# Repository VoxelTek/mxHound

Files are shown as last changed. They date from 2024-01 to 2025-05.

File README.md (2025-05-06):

# mxHound
### A Wii RTC-RVL ("MX chip") relocation flex



This flexible PCB aims to simplify the relocation of the Wii MX chip, to make creating portables that utilise it as easy as possible.

Due to the overlapping of the via used for the U10, I decided to also relocate it onto here. I also added a solder pad if U10 emulation (like what's featured on the RVL-PMS line) is used, or if U10 is located elsewhere. 

Additional pads were added for soft shutdown and the EXI bus, primarily for the RVL-DD.

This flex primarily reuses the original components found on the Wii motherboard, with the reference designators for the passive components matching the corresponding components from the Wii.

- R60 = 1kΩ, 0402 (1005 metric)
- D31 = 0603 (1608 metric) package, unknown specs
- C101, C102 = 5pF, 0402 (1005 metric)
- C98 = 100nF, 0402 (1005 metric)

To reduce space, the crystal has been swapped for a smaller one. Any crystal with a frequency of 32.768 kHz and a load capacitance of 4pF in a 2mm x 1.2mm package should work fine.

Some suitable replacements:

- ABS06-107-32.768KHZ-T ([Digikey](https://www.digikey.com.au/en/products/detail/abracon-llc/ABS06-107-32-768KHZ-T/4291565) | [Mouser](https://mou.sr/3IUZvTK))
- ECS-.327-CDX-1082 ([Digikey](https://www.digikey.com.au/en/products/detail/ecs-inc/ECS-327-CDX-1082/5875549) | [Mouser](https://mou.sr/3VA6LMf))

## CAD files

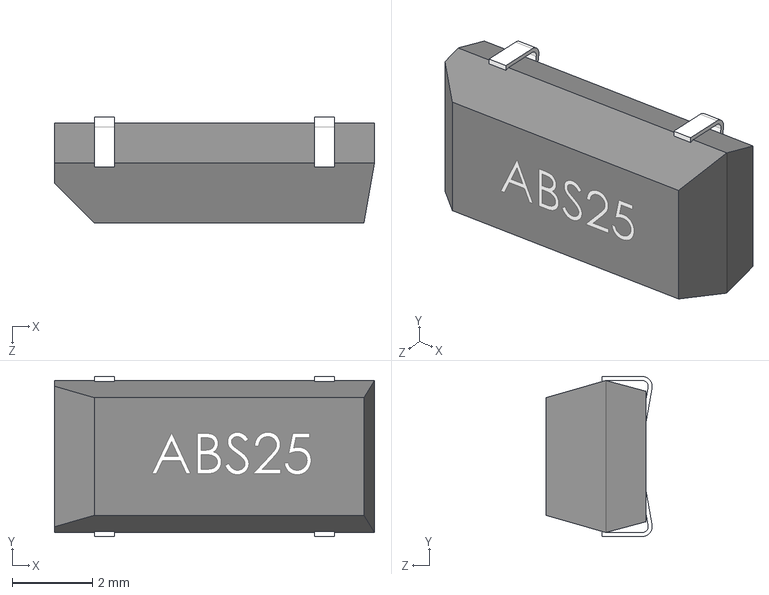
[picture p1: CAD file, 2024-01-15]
3D/ABS25-32.768KHZ-6-T.stp
8.00 x 4.00 x 2.66 mm

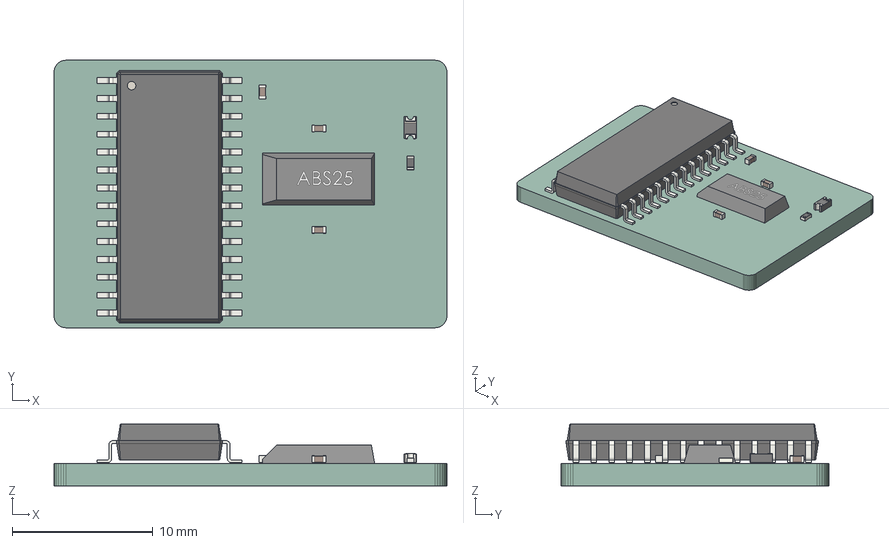
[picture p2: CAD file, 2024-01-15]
MXBreakout.step
27.9 x 19.0 x 4.40 mm
SOIC_28W_75x179mm_P127mm
D_0603
C_0402_1005Metric x 3
R_0402_1005Metric
ABS25
MXBreakout PCB

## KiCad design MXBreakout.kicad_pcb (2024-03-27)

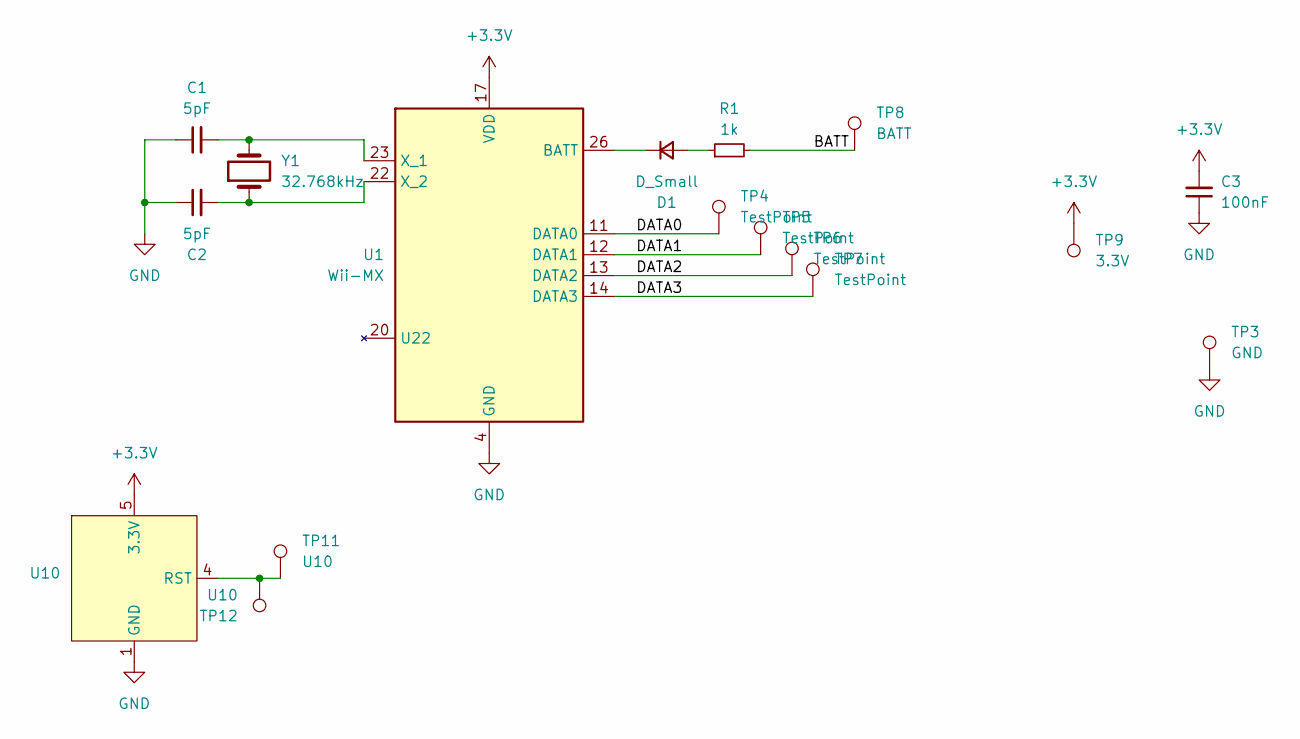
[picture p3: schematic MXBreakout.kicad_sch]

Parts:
C1, C2: 5pF; C_0402_1005Metric; MouserPart 81-GRM1555C1H5R0BA1D
C3: 100nF; C_0402_1005Metric
D1: D_Small; D_0603_1608Metric
R1: 1k; R_0402_1005Metric
TP3: GND; TestPoint_THTPad_D0.5mm_Drill0.35mm
TP4, TP5, TP6, TP7: TestPoint; TestPoint_THTPad_D0.5mm_Drill0.35mm
TP8: BATT; TestPoint_Pad_D1.0mm
TP9: 3.3V; TestPoint_Pad_D1.0mm
TP11: U10; TestPoint_THTPad_D0.5mm_Drill0.35mm
TP12: U10; TestPoint_Pad_D1.0mm
U1: Wii-MX; SOIC-28W_7.5x17.9mm_P1.27mm
U10: SOT-23-5
Y1: 32.768kHz; Crystal_SMD_2012-2Pin_2.0x1.2mm

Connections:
+3.3V: C3.2, TP9.1, U1.17 (VDD), U1.24 (VDD), U1.25 (VDD), U1.27 (VDD), U10.5 (3.3V)
/BATT: R1.2, TP8.1
/DATA0: TP4.1, U1.11 (DATA0)
/DATA1: TP5.1, U1.12 (DATA1)
/DATA2: TP6.1, U1.13 (DATA2)
/DATA3: TP7.1, U1.14 (DATA3)
GND: C1.1, C2.1, C3.1, TP3.1, U1.4 (GND), U1.16 (GND), U10.1 (GND), U10.2 (GND), U10.3 (GND); also elsewhere on the board
unnamed: D1.2 (A), R1.1
unnamed: D1.1 (K), U1.26 (BATT)
unnamed: C1.2, U1.23 (X_1), Y1.2
unnamed: C2.2, U1.22 (X_2), Y1.1
unnamed: TP11.1, TP12.1, U10.4 (RST)

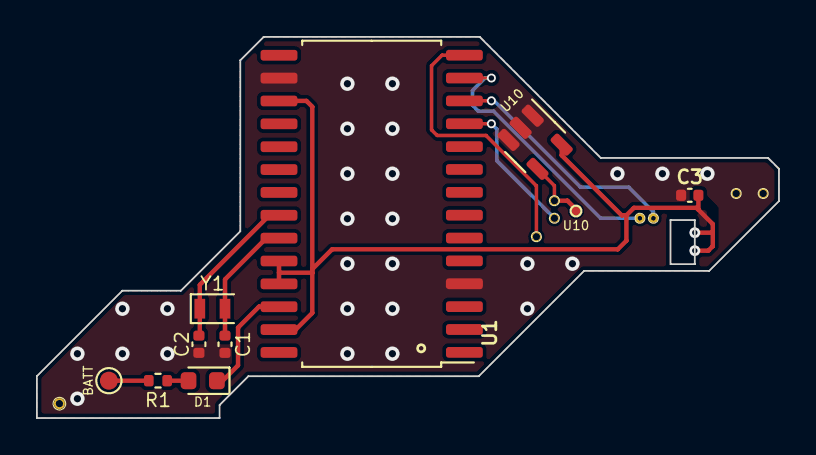
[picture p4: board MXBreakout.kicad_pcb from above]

Board: 2 copper layers, 41.2 x 21.2 mm, 17 parts (0 on the bottom side), 12 nets.

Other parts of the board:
TP3#2: GND; TestPoint_THTPad_D0.5mm_Drill0.35mm

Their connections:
GND: TP3#2.1; also elsewhere on the board

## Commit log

2024-01-15 initial changes
    [MXBreakout.kicad_pcb, MXBreakout.kicad_sch]
2024-01-15 nearing completion
    [MXBreakout-B_Cu.gbr, MXBreakout-B_Mask.gbr, MXBreakout-B_Paste.gbr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]
2024-03-27 Adjust PCB 3D view
    [MXBreakout.kicad_pcb]
2024-03-27 Reorganisation and gerber regeneration
    [MXBreakout-B_Cu.gbr, MXBreakout-B_Mask.gbr, MXBreakout-B_Paste.gbr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]
2024-03-27 Minor track tidy
    [MXBreakout.kicad_pcb]
2024-03-30 Minor cleanup
    [MXBreakout.kicad_sch]
2024-04-01 Fix pad alignment, add soft shutdown
    [MXBreakout.kicad_sch]
2024-04-01 Regenerate gerber files
    [MXBreakout-B_Cu.gbr, MXBreakout-B_Mask.gbr, MXBreakout-B_Paste.gbr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]
2024-04-02 Add cutouts, regenerate gerbers
    [MXBreakout-B_Cu.gbr, MXBreakout-B_Mask.gbr, MXBreakout-B_Paste.gbr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]
2024-05-10 Add pads for EXI bus, primarily for RVL-DD
    [MXBreakout.kicad_sch]
2024-05-13 Clean up PCB, regenerate gerbers
    [MXBreakout-B_Cu.gbr, MXBreakout-B_Mask.gbr, MXBreakout-B_Paste.gbr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]
2025-05-06 Misc improvements to flex
    [MXBreakout.kicad_sch]
2025-05-10 Regenerate gerbers
    [MXBreakout-B_Cu.gbr, MXBreakout-B_Mask.gbr, MXBreakout-B_Paste.gbr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]
2025-05-22 Regenerated gerbers due to weird issue
    [MXBreakout-B_Cu.gbr, MXBreakout-B_Mask.gbr, MXBreakout-B_Paste.gbr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]
